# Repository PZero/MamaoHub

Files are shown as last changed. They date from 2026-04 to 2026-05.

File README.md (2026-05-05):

# MaMaoHub: NMEA 0183 Hub per Imbarcazioni

## Proposito del Progetto
Il progetto **MaMaoHub** ha l'obiettivo di centralizzare, multiplexare e distribuire i dati di navigazione NMEA 0183 su una barca, rendendoli fruibili sia via hardware (RS485) che via software (Wi-Fi/Web).

L'hub funge da ponte tra la strumentazione tradizionale e le moderne applicazioni di navigazione su tablet/smartphone, fornendo al contempo una dashboard web-based per il monitoraggio in tempo reale.

## Architettura del Sistema

### Diagramma di Connettività
```mermaid
graph TD
    subgraph Ingressi["1. Ingressi Strumentazione"]
        Vento[Stazione Vento]
        Bussola[Bussola]
    end

    subgraph Waveshare["2. Interfaccia Waveshare 4Ch USB-RS485"]
        Port1[Porta 1]
        Port2[Porta 2]
        Port3[Porta 3]
        Port4[Porta 4 - LIBERA]
    end

    subgraph RPi["3. Hub Centrale (Raspberry Pi Zero 2 W)"]
        SK[Signal K Server]
        UPS[UPS Geekworm X306] -- Power --> SK
        
        subgraph Funzionalita["Servizi Integrati"]
            WiFi[Distribuzione Wi-Fi: TCP/UDP]
            WebDash[Web Dashboard App]
        end
    end

    subgraph Bridge["4. Modulo TTL-RS485"]
        TTL[Uscita Seriale UART]
    end

    subgraph Nav["5. Navigatore (Esterno)"]
        Nav_Device[Processore Navigatore]
    end

    %% Flusso Dati Ingresso
    Vento --> Port1
    Bussola --> Port2
    Port1 & Port2 -- USB --> SK
    
    %% Multiplex A+B verso Navigatore
    SK -- "Multiplex A+B" --> TTL
    TTL -- "RS485" --> Nav_Device
    
    %% Rientro Segnale Completo
    Nav_Device -- "Segnale Completo" --> Port3
    Port3 -- USB --> SK
    
    %% Output Wi-Fi e Web
    SK -- "Parsing Segnale Completo" --> Funzionalita
    WiFi --> Tablet[Tablet / Smartphone]
    WebDash --> Tablet
```

### Elenco Componenti Hardware
1.  **Cervello**: Raspberry Pi Zero 2 W.
2.  **Alimentazione**: Geekworm X306 v1.3 UPS (con supporto allo shutdown controllato).
3.  **Hub Seriale**: Waveshare 4-Channel RS485 to USB.
4.  **Modulo RS485 Aggiuntivo**: Modulo TTL to RS485 collegato via UART (GPIO 14/15). Utilizzato per inviare il mix Vento+Bussola al Navigatore.
5.  **Navigatore (Esterno)**: Device che riceve il mix Vento+Bussola dal modulo TTL e produce il Segnale Completo per la Porta 3.

### Flusso Dati (Loop-back)
1.  **Ingresso**: MaMaoHub riceve i dati da **Stazione Vento** e **Bussola** tramite le porte 1 e 2 del Waveshare.
2.  **Multiplex**: Signal K combina i dati e li invia al **Navigatore** tramite il **modulo TTL-RS485** (UART).
3.  **Elaborazione Esterna**: Il Navigatore riceve il mix, lo processa e restituisce il **Segnale Completo** alla porta 3 del Waveshare.
4.  **Distribuzione Interna**: MaMaoHub riceve il Segnale Completo e abilita i servizi integrati:
    *   **Wi-Fi**: Distribuzione via TCP (10110) e UDP Broadcast per app come Navionics.
    *   **Web**: Dashboard integrata accessibile via browser per il monitoraggio.
5.  **Porta 4**: Rimane libera per usi futuri.

## Guida Passo-Passo all'Installazione (Primo Setup)

Segui questi passaggi per preparare la tua prima scheda SD e rendere operativo MaMaoHub.

### Fase 1: Preparazione della Scheda SD
1. **Scarica lo strumento**: Scarica e installa [Raspberry Pi Imager](https://www.raspberrypi.com/software/) sul tuo PC/Mac.
2. **Scegli il Sistema Operativo**:
   * Clicca su **CHOOSE OS**.
   * Seleziona **Raspberry Pi OS (other)** -> **Raspberry Pi OS Lite (64-bit)**.
3. **Configura le Impostazioni (Cruciale)**:
   * Clicca sull'icona dell'ingranaggio (o premi `Ctrl+Shift+X`).
   * **Hostname**: Imposta `mamaohub.local`.
   * **SSH**: Seleziona "Enable SSH" e scegli "Use password authentication".
   * **Set username and password**: Crea un utente (es. username: `pi`, password: `tua_password`).
   * **Configure wireless LAN**: Inserisci il nome (SSID) e la password del Wi-Fi della tua barca o del tuo hotspot cellulare.
   * **Set locale settings**: Imposta il fuso orario e il layout della tastiera su `it`.
4. **Scrivi**: Inserisci la micro SD nel PC e clicca su **WRITE**.

### Fase 2: Primo Avvio e Accesso
1. Inserisci la micro SD nel Raspberry Pi Zero 2 W e alimentalo tramite l'UPS Geekworm.
2. Attendi circa 2-3 minuti per il primo avvio.
3. Apri un terminale sul tuo PC (PowerShell su Windows, Terminale su Mac) e digita:
   ```bash
   ssh pi@mamaohub.local
   ```
   *(Sostituisci `pi` con l'username che hai scelto. Se l'utente è `admin`, usa `ssh admin@mamaohub.local`).*

### Fase 3: Installazione Automatizzata MaMaoHub
Una volta entrato nel Raspberry Pi, copia e incolla questi comandi uno alla volta:

```bash
# 1. Installa git (se non presente)
sudo apt update && sudo apt install -y git

# 2. Scarica il progetto (usando il tuo token per l'autenticazione)
git clone https://<YOUR_TOKEN>@github.com/PZero/MamaoHub.git

# 3. Entra nella cartella ed esegui l'installazione
cd MamaoHub
chmod +x scripts/install.sh
sudo ./scripts/install.sh
```

### Fase 4: Verifica e Accesso ai Servizi
Al termine dell'installazione e dopo il riavvio richiesto:
* **Signal K Dashboard**: Apri il browser e vai su `http://mamaohub.local:3000`.
* **Wi-Fi Failover**: Se porti il Pi in un luogo dove non c'è Wi-Fi, dopo 60 secondi vedrai apparire una rete chiamata **MaMaoHub-Hotspot**. Collegati con password `mamaohub123` e naviga su `http://192.168.4.1:3000`.

---

## 🖥️ MaMaoDash - La Dashboard Integrata

MaMaoHub include una dashboard web professionale sviluppata su misura, chiamata **MaMaoDash**, progettata specificamente per la navigazione e ottimizzata per schermi di tablet e smartphone.

### Screenshot
*(Aggiungi qui i tuoi screenshot: salva le immagini nella cartella `docs/` o nella root e sostituisci questi link)*
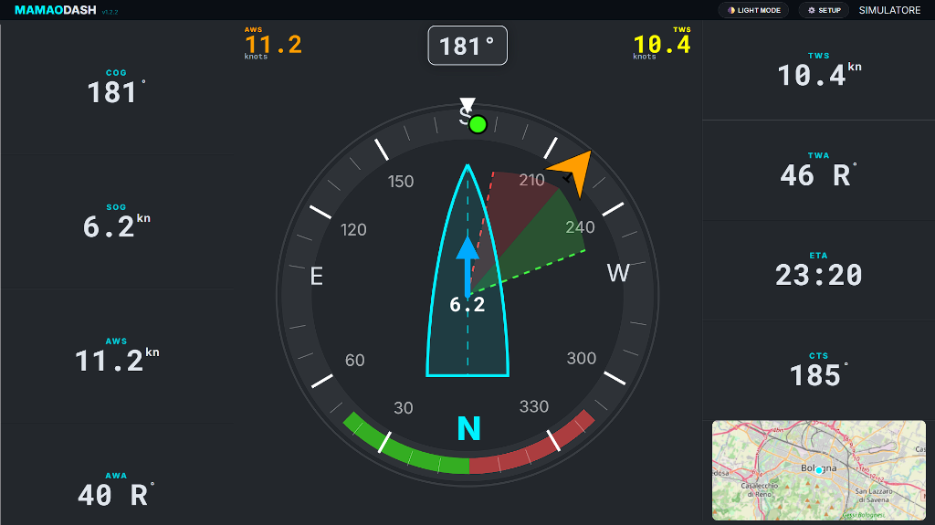
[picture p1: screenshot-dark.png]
Dashboard Dark Mode
*   
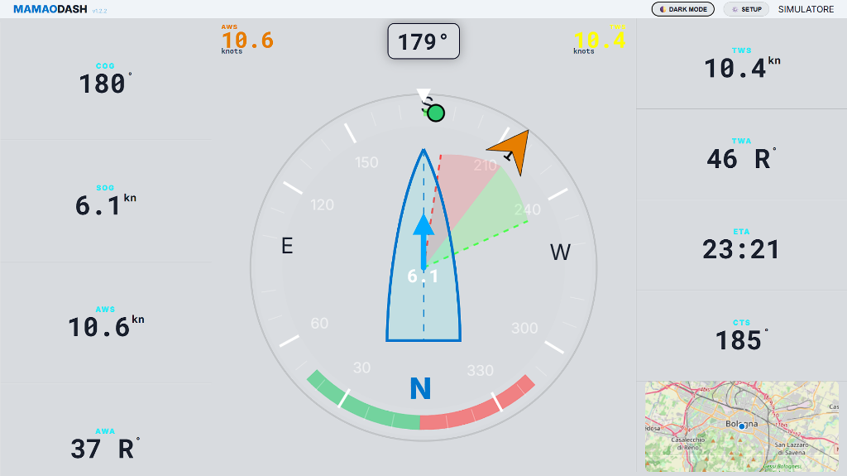
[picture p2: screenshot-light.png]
Dashboard Light Mode
*   
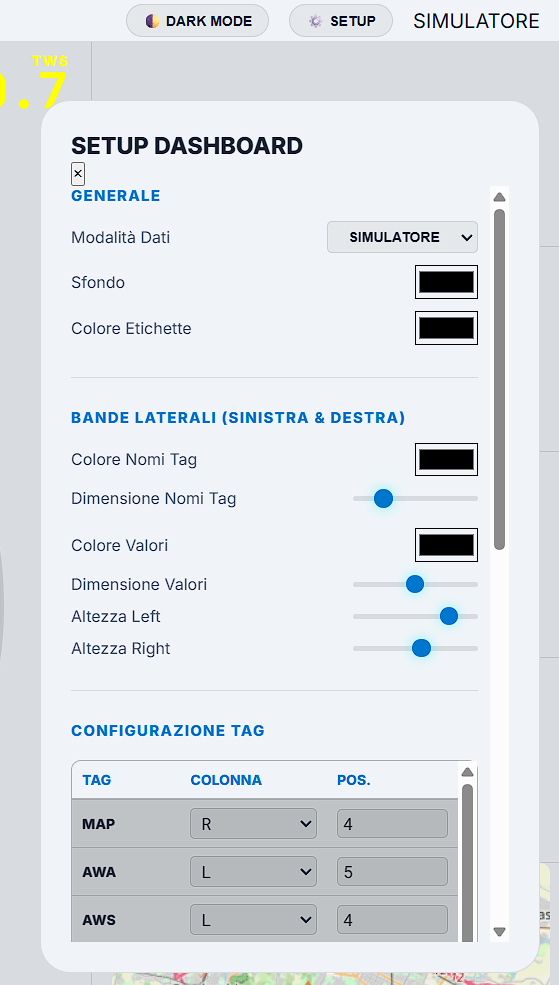
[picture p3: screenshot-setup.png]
Menu Setup
*   

### Caratteristiche Principali
* **NavDisplay Centrale (Racing Style)**: Un widget visivo vettoriale fluido (SVG) che mostra in tempo reale:
  * Prua (HDG) e Rotta (COG).
  * Vettore del Vento Apparente (AWA/AWS) e Reale (TWA/TWS) con layline dinamiche.
  * Vettore di Velocità (SOG) e indicatore di rotta verso il Waypoint (BTW) con arco direzionale.
* **Integrazione Signal K**: Si collega automaticamente al server Signal K sulla porta `3000` via WebSocket per ricevere telemetria in tempo reale dalla strumentazione NMEA 0183 di bordo.
* **Simulatore Integrato**: Perfetto per testare l'interfaccia a casa o su GitHub Pages. Genera dati nautici e derive realistiche senza bisogno di hardware connesso.
* **Layout Totalmente Flessibile**: Scegli quali dati (COG, SOG, AWS, DTG, ETA, ecc.) mostrare nella colonna destra o sinistra, definendone l'ordine di apparizione.
* **Colori e Temi**: Passaggio istantaneo tra **Dark Mode** (ideale per la navigazione notturna) e **Light Mode**. I colori di layline, vettori vento, barca ed etichette sono modificabili a piacimento.

### Installazione e Avvio
Se hai seguito la *Guida Passo-Passo all'Installazione* vista sopra, la dashboard è già pronta sul tuo Raspberry Pi. 
Basta aprire un browser collegato al Wi-Fi della barca su: `http://mamaohub.local:8080` (oppure `http://192.168.4.1:8080` se in modalità hotspot).

**Per Sviluppo e Test Locale (PC / Mac):**
1. Clona il repository: `git clone https://github.com/PZero/MamaoHub.git`
2. Entra nella cartella: `cd MamaoHub`
3. Installa le dipendenze base: `npm install`
4. Avvia il server Node.js: `npm start`
5. Apri il browser su: `http://localhost:8080`

### ⚙️ Menu SETUP e Persistenza Impostazioni
Cliccando sul tasto **SETUP** (in alto a destra), si apre un pannello laterale da cui puoi configurare:
*   **Colori Globali**: Sfondo e testo base.
*   **Bande Laterali**: Dimensione del testo e altezza dei blocchi.
*   **Configurazione TAG**: Scegli la colonna (Left/Right) e la posizione di ogni valore NMEA.
*   **NavDisplay**: Scala del widget centrale (zoom) e personalizzazione dei colori vettoriali.

> **Importante: Dove vengono salvate le impostazioni?**
> * **Su GitHub Pages (Senza server)**: Se apri il progetto direttamente da Git, le impostazioni vengono salvate localmente nel browser (`localStorage`). Non verranno condivise con altre schede in Incognito o altri browser.
> * **Su Raspberry Pi (Produzione)**: Il server integrato salva le preferenze nel file `dashboard/settings.json`. In questo modo, **qualsiasi browser o tablet** che si collegherà alla rete della barca visualizzerà lo stesso identico layout e gli stessi colori.

---

## Funzionalità Chiave
*   **Gestione Alimentazione**: Shutdown automatico in assenza di alimentazione esterna per proteggere il file system. Auto-boot al ritorno della corrente.
*   **Standard Industriale**: Utilizzo di Signal K come motore di elaborazione dati per massima flessibilità.
*   **Accessibilità**: Dashboard personalizzate raggiungibili via browser da qualsiasi dispositivo connesso alla rete della barca.
*   **Specifiche Software**:
    *   **Sistema Operativo**: Raspberry Pi OS Lite (64-bit) basata su **Debian Bookworm** (ultima versione stabile). Una versione leggera ottimizzata per l'uso "headless" (senza interfaccia grafica).
    *   **Ambiente di Esecuzione**: **Node.js (LTS)**, necessario per far girare il cuore del sistema.
    *   **Data Server**: **Signal K Server**, lo standard open-source per l'interoperabilità dei dati marini.
    *   **Plugin Necessari**:
        *   `signalk-to-nmea0183`: Fondamentale per convertire i dati Signal K nel formato NMEA 0183 da inviare all'uscita fisica.
        *   `instrumentpanel`: Per la visualizzazione dei dati in formato analogico/digitale su browser.
        *   `signalk-kip`: Dashboard avanzata con supporto per temi scuri (ideale per la navigazione notturna).
        *   `signalk-freeboard-sk`: Per integrare mappe nautiche e posizionamento.
    *   **Utility di Sistema**:
        *   **NetworkManager**: Gestione robusta della rete Wi-Fi (configurazione Access Point o connessione a router di bordo).
        *   **Udev**: Per l'assegnazione di nomi univoci alle porte USB del Waveshare.
        *   **mamao-ups (Python/Service)**: Script personalizzato e servizio systemd per il monitoraggio del GPIO e lo shutdown sicuro.
        *   **kplex (opzionale)**: Multiplexer NMEA 0183 puro per routing ad altissime prestazioni e bassa latenza.
        *   **Git**: Fondamentale per il versionamento di `/etc/udev/rules.d/`, `settings.json` di Signal K e gli script di sistema.

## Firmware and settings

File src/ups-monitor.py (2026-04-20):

#!/usr/bin/env python3
# ups-monitor.py - Monitoraggio alimentazione per Geekworm X306
# Lo script effettua lo shutdown sicuro se manca l'alimentazione esterna.

import RPi.GPIO as GPIO
import os
import time

# Pin GPIO per il segnale di Power Loss (PLD)
# Per X306 v1.3 solitamente è il GPIO 6
PIN_PLD = 6

# Tempo di attesa (secondi) prima di spegnere
SHUTDOWN_DELAY = 30

def setup():
    GPIO.setmode(GPIO.BCM)
    # Impostiamo il pin come ingresso con Pull-up interno
    GPIO.setup(PIN_PLD, GPIO.IN, pull_up_down=GPIO.PUD_UP)

def monitor():
    print(f"Monitoraggio UPS avviato sul pin GPIO {PIN_PLD}...")
    while True:
        # Se il pin PLD va a LOW, significa che manca l'alimentazione esterna
        if GPIO.input(PIN_PLD) == GPIO.LOW:
            print("ATTENZIONE: Alimentazione esterna assente!")
            print(f"Shutdown programmato tra {SHUTDOWN_DELAY} secondi...")
            
            # Verifica se la corrente torna durante il delay
            for i in range(SHUTDOWN_DELAY):
                time.sleep(1)
                if GPIO.input(PIN_PLD) == GPIO.HIGH:
                    print("Ripristino alimentazione. Shutdown annullato.")
                    break
            else:
                # Se il ciclo for finisce senza break, spegni
                print("Esecuzione shutdown sicuro ora.")
                os.system("sudo shutdown now")
                break
        
        time.sleep(2)

if __name__ == "__main__":
    try:
        setup()
        monitor()
    except KeyboardInterrupt:
        print("Monitoraggio interrotto.")
    finally:
        GPIO.cleanup()

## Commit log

2026-04-20 Update: Added TTL-RS485 bridge for Input 3 and refined data flow
2026-04-20 Update: Redesigned diagram with Waveshare subgraph and clearer flow
2026-04-20 Update: Corrected physical routing (A+B via UART, Port 4 unallocated)
2026-04-20 Update: Added KiCad schematic and visual wiring layout
    [MaMaoHub_Schematic.kicad_sch]
2026-04-20 Update: Added professional 3D render and detailed hardware pinout v2.0
    [MaMaoHub_Schematic.kicad_sch]
2026-04-20 Automazione setup, Auto-Hotspot, udev rules e monitoraggio UPS
    [MaMaoHub_Schematic.kicad_sch]
2026-05-05 feat: add BTW waypoint indicator with red/green steering arc
2026-05-05 style: move knots below wind values and maximize font to XXL
